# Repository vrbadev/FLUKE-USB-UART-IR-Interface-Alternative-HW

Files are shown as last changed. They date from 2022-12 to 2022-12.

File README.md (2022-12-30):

# FLUKE ScopeMeter USB-UART IR Interface (HW & SW Project)
 This is an open-source hardware and software project intended to replace the official overpriced FLUKE PM9080 InfraRed RS-232 Interface. 
 
 The final USB-UART IR interface mounted on a custom 3D printed holder is connected to the FLUKE 189 True RMS Multimeter and shown in the image below. The working principle is simple, the UART TX line drives an isolating IR diode and the UART RX line is driven by an isolating IR phototransistor.

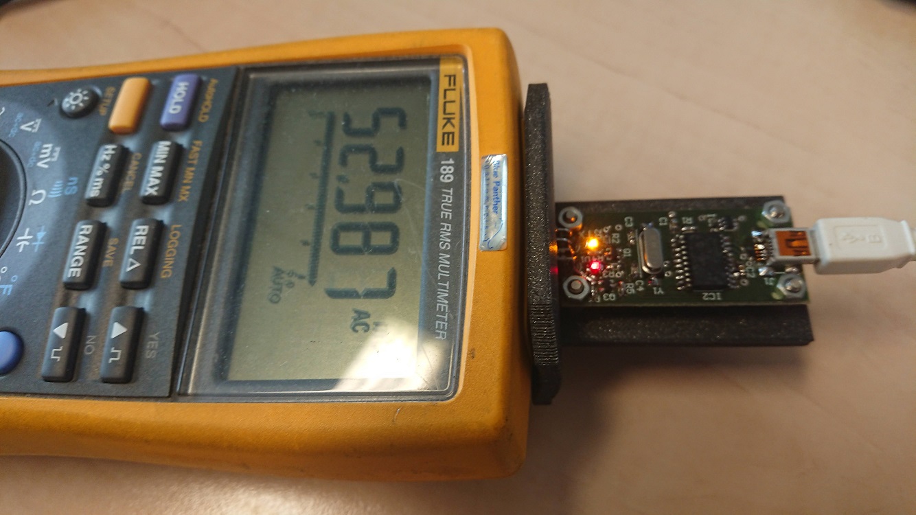
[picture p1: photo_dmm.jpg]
The USB-UART IR interface connected to the FLUKE 189 True RMS Multimeter


## Repository Contents

* **Hardware folder** - Contains complete Altium Designer 6 PCB project, including PDF schematic and layout visualisations.
* **Software fodler** - Contains example Python codes (using pyserial package for serial communication).
* **3D Print folder** - Contains Blender file for the printable holder, including model STEP file. There is an older version (on the photo above) and a newer version with a protection box hiding the PCB board completely.
* **Gerber ZIP file** - An archive containing generated production files for the PCB.
* **Conf file** - Configuration file for the MCP2200 Configuration Utility (which can be downloaded [from the official Microchip site](https://www.microchip.com/en-us/product/MCP2200)).

## Bill Of Material (BOM)

| **IDs** | **Pcs** | **Value/Type** | **Description** | **Package** |
|---|---|---|---|---|
| C1 | 1 | 100n | Ceramic capacitor | 0603 |
| C2,C3 | 2 | 22p | Ceramic capacitor | 0603 |
| C4 | 1 | 330n | Ceramic capacitor | 0603 |
| D1,D2 | 2 | Red/green | LED diode | 0603 |
| D3 | 1 | 15400385A3590  | IR diode 850nm 50mA | T-1 (3mm) |
| IC1 | 1 | USBLC6-2 | ESD protection for USB | SOT23-6 |
| IC2 | 1 | MCP2200-I/SO | USB-UART interface bridge | SOIC-20 |
| J1 | 1 | 65100516121 | Mini USB Type B | 5-pin |
| R1,R5 | 2 | 1k | Resistor | 0603 |
| R2,R3 | 2 | 470R | Resistor | 0603 |
| R4 | 1 | 100R | Resistor | 0603 |
| R6 | 1 | 10k | Resistor | 0603 |
| Q1 | 1 | BSS138 | N-Channel logic-level MOSFET | SOT23-3 |
| Q2 | 1 | BPW85 | IR phototransistor 850nm | T-1 (3mm) |
| Q3 | 1 | BC847B | NPN general-purpose transistor | SOT23-3 |
| Y1 | 1 | 12MHz | SMD crystal | HC-49/US |

## Photo of the Assembled Boards

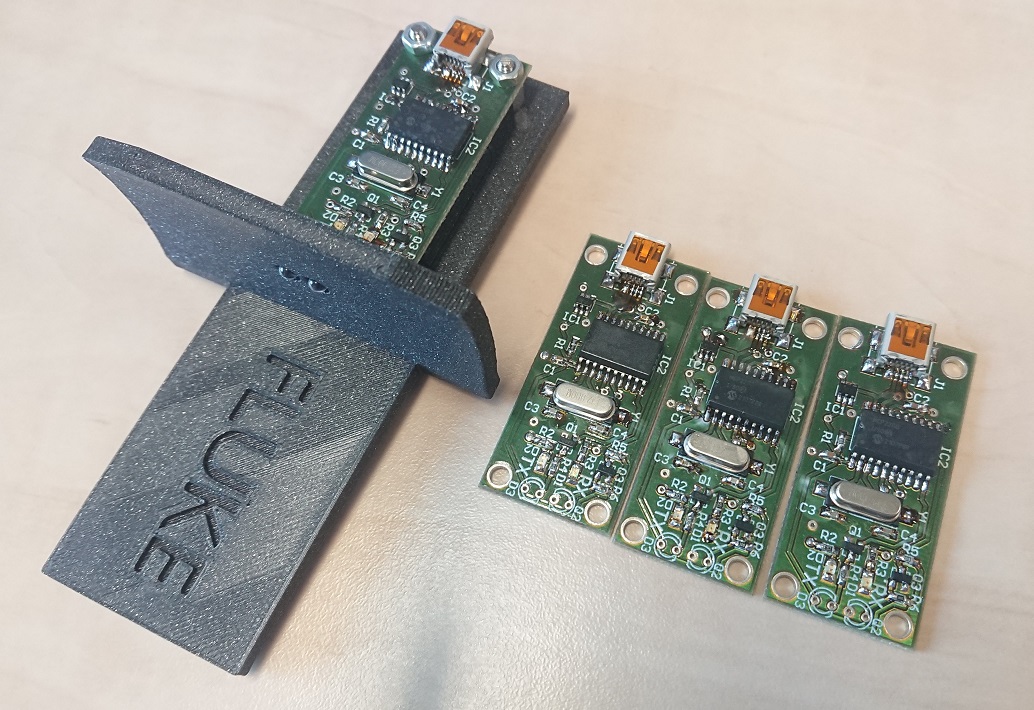
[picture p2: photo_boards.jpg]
The assembled boards


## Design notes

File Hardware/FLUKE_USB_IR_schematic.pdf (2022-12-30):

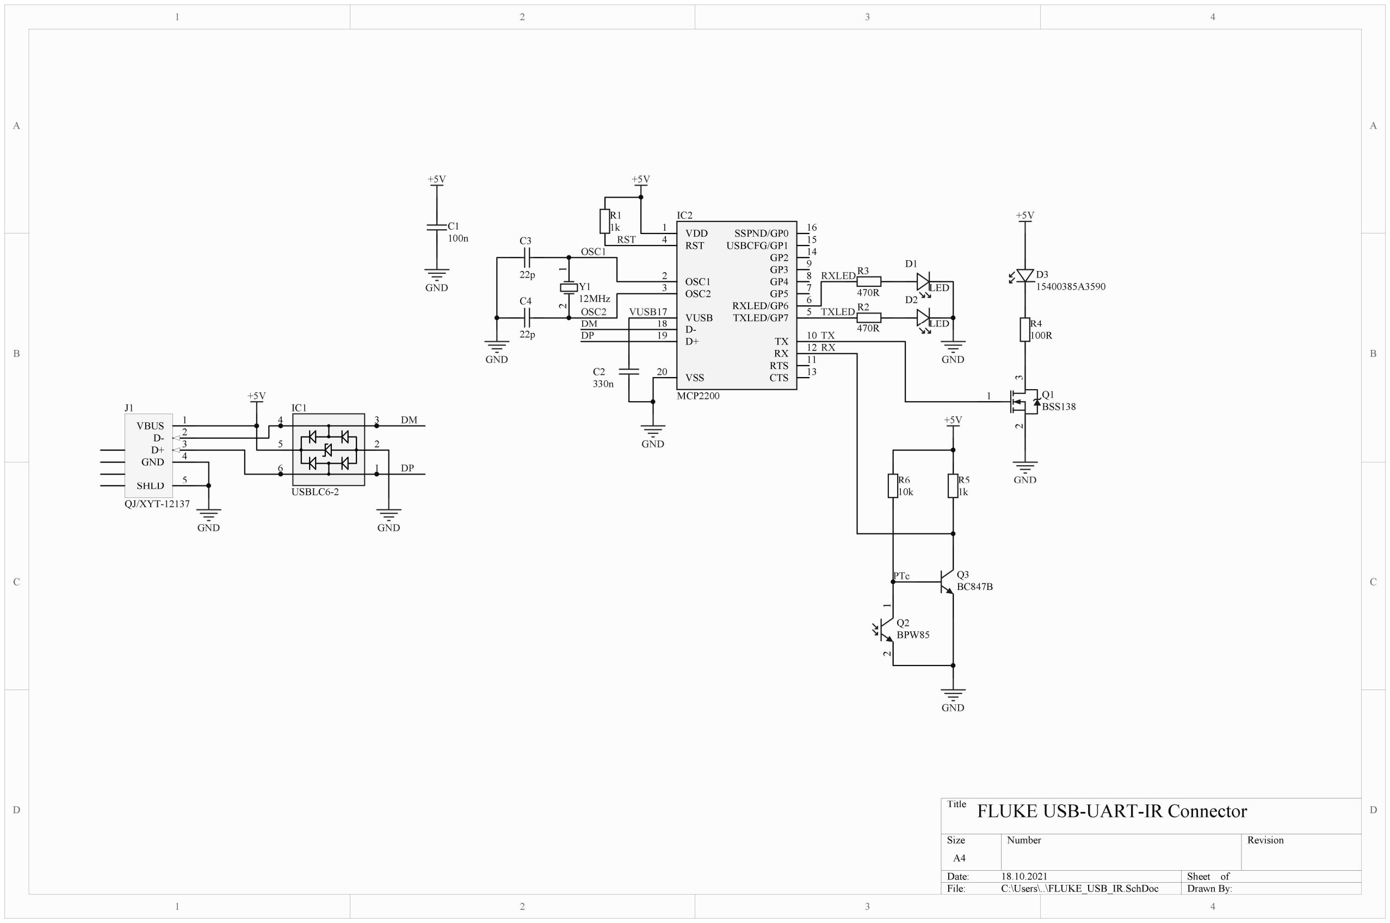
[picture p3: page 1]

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
Title

Size | Number | Revision
A4
Date: | 18.10.2021 | Sheet of
File: | C:\Users\..\FLUKE_USB_IR.SchDoc | Drawn By:

1

2

4 3

5

6

IC1

USBLC6-2

VBUS | 1
D- | 2
D+ | 3
GND | 4
SHLD | 5

J1

QJ/XYT-12137

VDD 1
RST 4

OSC1 2
OSC2 3

D+ 19 D- 18

VSS 20

SSPND/GP0 | 16
USBCFG/GP1 | 15
GP2 | 14
GP3 | 9
GP4 | 8
GP5 | 7
RXLED/GP6 | 6
TXLED/GP7 | 5
TX | 10
RX | 12
RTS | 11
CTS | 13

VUSB 17

IC2

+5V | MCP2200

+5V

GND | GND

GND

1k

R1

GND

470R

R2

470R ¹

R3 2
Y1
12MHz

DM

DP

100n

C1

330n

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
DP | 2

1 3
Q1
BSS138

D1

LED
D2

LED

GND

GND

+5V

100R

R4

D3
15400385A3590

1 2
Q2
BPW85

GND

+5V

1k

R5
10k

R6

OSC1

OSC2

RST

RXLED

TXLED

TX
RX

PTc

VUSB

# FLUKE USB-UART-IR Connector

Q3
BC847B

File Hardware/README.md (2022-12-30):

# Hardware Design
 
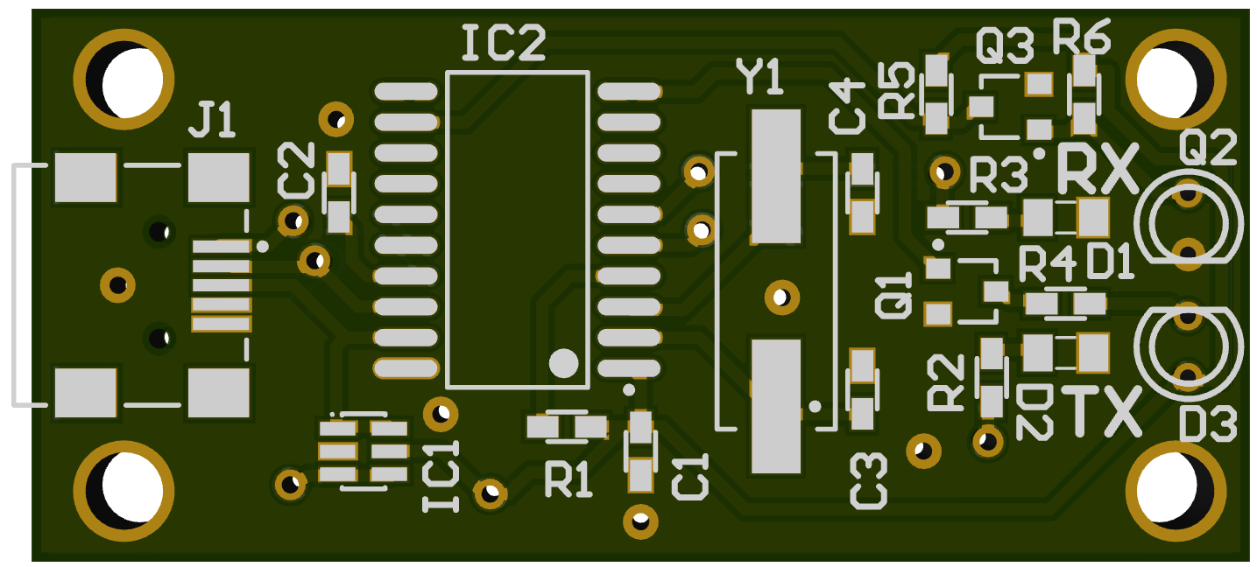
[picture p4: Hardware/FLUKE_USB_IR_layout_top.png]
Top layout
 
 
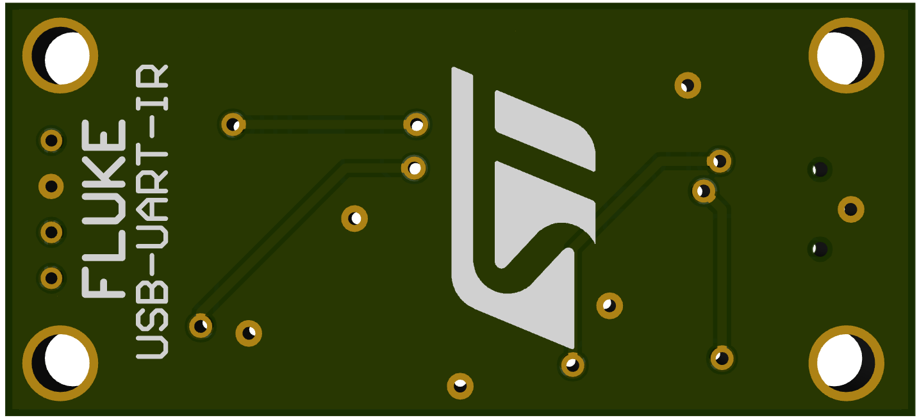
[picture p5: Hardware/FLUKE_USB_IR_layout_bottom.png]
Bottom layout


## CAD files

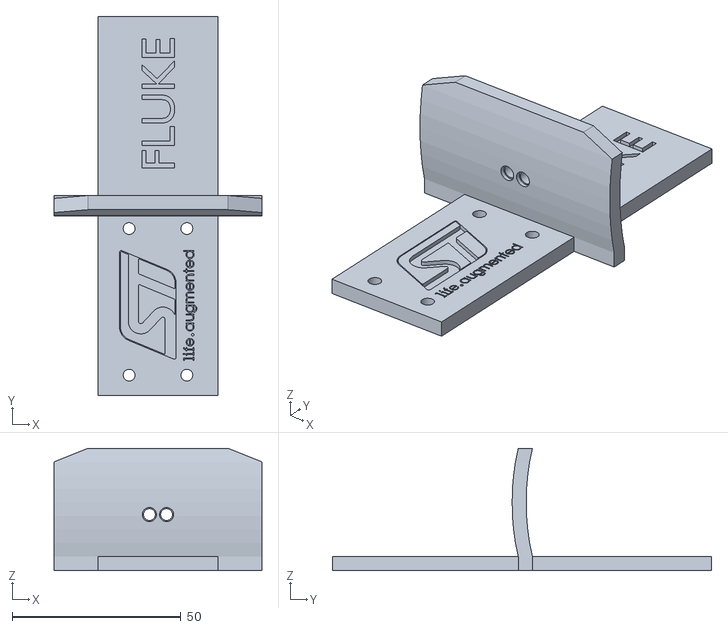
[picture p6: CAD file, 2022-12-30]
3D Print/fluke_usb_ir-holder.stl
61.5 x 112.2 x 36.2

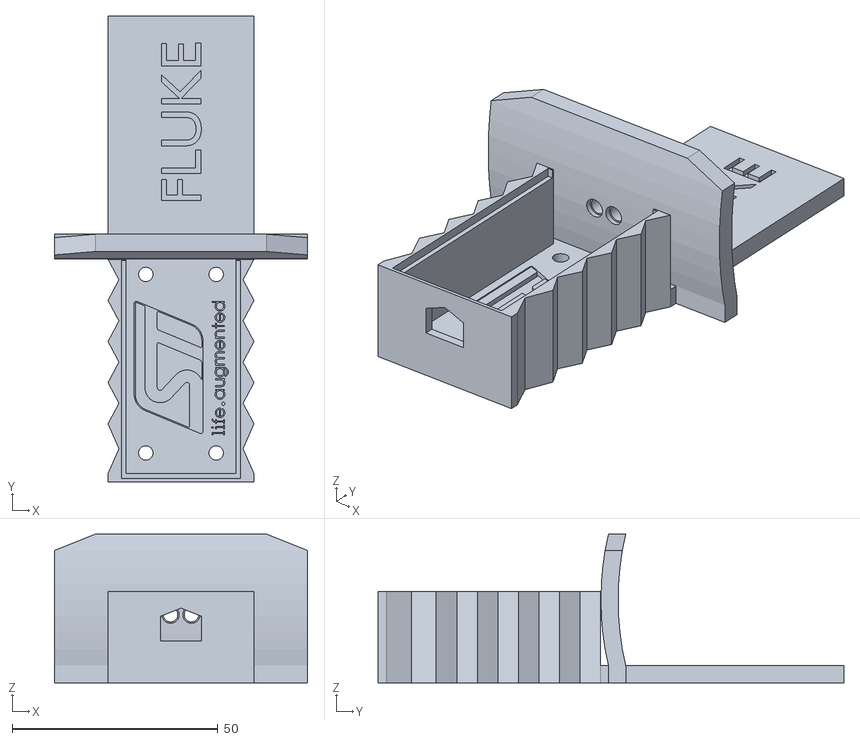
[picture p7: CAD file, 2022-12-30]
3D Print/fluke_usb_ir-holder_v2.stl
61.5 x 113.2 x 36.2

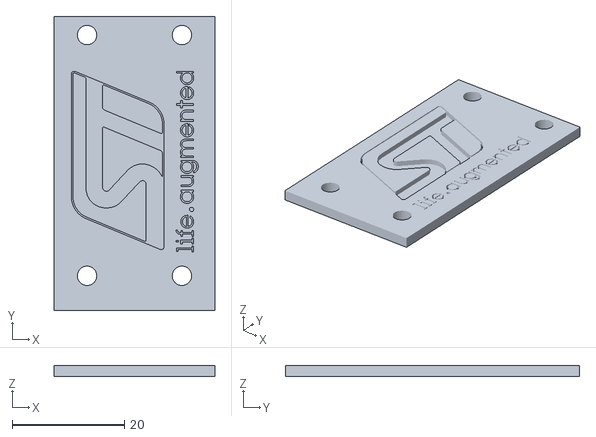
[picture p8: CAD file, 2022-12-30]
3D Print/fluke_usb_ir-box_top.stl
28.7 x 52.5 x 1.98

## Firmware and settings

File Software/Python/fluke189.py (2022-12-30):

# -*- coding: utf-8 -*-
"""
Created on Mon Oct 18 15:06:14 2021
@author: Vojtech Vrba (vrba.vojtech@gmail.com)

USB-UART-IR Commands for FLUKE 189 True RMS Multimeter
Required python dependency: pyserial
Working baudrate: 9600 bps

Working commands:
    - DS (Default Setup)
    - ID (Identification) - response: FLUKE 189, V2.02,0084750006<\r>
    - PS (Program Setup) - ???
    - QM (Query Measurement) - responds with current measurement
    - QS (Query Setup) - responds with setup?
    - RI (Reset Instrument) - resets instrument
"""

import serial

class Fluke189:
    def __init__(self, port):
        self.port = port
        self.com = None
    
    def connect(self):
        if not self.com:
            try:
                self.com = serial.Serial(self.port, baudrate=9600, bytesize=serial.EIGHTBITS, parity=serial.PARITY_NONE, stopbits=serial.STOPBITS_ONE, timeout=1)
                print("Success: Connected to serial COM port", self.com.name)
            except serial.SerialException as e:
                print("Error:", e)
        else:
            print("Error: Serial COM port already connected")
    
    def disconnect(self):
        if self.com:
            self.com.close()
            self.com = None
            print("Success: Serial COM port disconnected")
        else:
            print("Error: Serial COM port already disconnected")
            
    def send_command(self, cmd):
        if self.com:
            self.com.write(str.encode(cmd) + b'\r')
            parts = self.com.readline().decode().split("\r")
            if parts[0] != cmd:
                print("Error: No echo on RX, maybe the adapter is not connected to the multimeter?")
                return
            if len(parts[1]) == 0:
                print("Error: No status response, maybe multimeter is offline?")
                return
            if int(parts[1]) == 0:
                if len(parts[2]) > 0:
                    return parts[2]
                else:
                    return
            else:
                print("Error: Unknown command", cmd)
                return
        else:
            print("Error: Serial COM port is disconnected")
    
    def reset_instrument(self):
        self.send_command("RI")
    
    def identification(self):
        return self.send_command("ID")
    
    def query_measurement(self):
        """
        Query measurement from the multimeter.
        When wrong mode is selected or error occurs, then returns None.

        Returns triplet
        -------
        quant : str
            Symbol representing measured quantity (R, U, I, T, G, C; where U, I with AC/DC/AC+DC).
        val : float
            Value of the quantity in base units or +-INF when Out of Range occurs.
        units : str
            Base unit of the measured quantity (Ohm, V, A, Deg C/Deg F, S, F).

        """
        r = self.send_command("QM")
        if r is None:
            return None
        try:
            r.index("- OFF -")
            return
        except ValueError:
            pass
        p1 = r.split(",", 1)
        try:
            oor = p1[1].index("Out of range.")
            units = p1[1][oor+14:].strip()
            if units[0] in "kMmun":
                units = units[1:]
            val = float('inf') if p1[1][0] == "+" else float('-inf')
        except ValueError:
            p2 = p1[1].split(" ", 1)
            val = float(p2[0])
            units = p2[1].strip()
            if units[0] == "k":
                val *= 1e3
            elif units[0] == "M":
                val *= 1e6
            elif units[0] == "m":
                val *= 1e-3
            elif units[0] == "u":
                val *= 1e-6
            elif units[0] == "n":
                val *= 1e-9
            if units[0] in "kMmun":
                units = units[1:]
                
        if units == "Ohms":
            quant = "R"
            units = "Ohm"
        elif units == "S":
            quant = "G"
        elif units[:3] == "Deg":
            quant = "T"
        elif units[0] == "V":
            quant = "U" + units[1:]
            units = units[0]
        elif units[0] == "A":
            quant = "I" + units[1:]
            units = units[0]
        elif units == "Farads":
            units = "F"
            quant = "C"
        elif units == "dBV":
            units = "dB"
            quant = "U"
            
        return quant, val, units

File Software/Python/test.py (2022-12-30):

# -*- coding: utf-8 -*-
"""
Created on Mon Oct 18 16:02:10 2021
@author: Vojtech Vrba (vrba.vojtech@gmail.com)

Test script for FLUKE 189 True RMS Multimeter UART communication.

Python lib dependency: pyserial
Install in command line with: pip install pyserial-3.5-py2.py3-none-any.whl
"""

from fluke189 import Fluke189
from datetime import datetime

if __name__ == "__main__":
    fluke = Fluke189("COM9")
    fluke.connect()
    
    print("Identification:", fluke.identification())
    
    data = list()
    
    while True:
        #print("Measurement no.", i, ":", fluke.query_measurement())
        ts = datetime.now().timestamp()
        m = fluke.query_measurement()
        print(ts, m)
        data.append((ts, m))
        #time.sleep(0.5)
        
    fluke.disconnect()
    
